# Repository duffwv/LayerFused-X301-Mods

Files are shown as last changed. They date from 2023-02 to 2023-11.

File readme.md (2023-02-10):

# LayerFused X301

These are my mods for the LayerFused X301.

* [Blind Joint](./blind-joint/)
* [BigTree-Tech Smart Filament Sensor Mount](./btt-smart-filament-sensor/)
* [BigTree-Tech TFT3.5 SPI Display Mount](./btt-tft35-spi-display-mount/)
* [BigTree-Tech Manta MB8 Mount](./electronics-enclosure/board-mounts/)
* [BigTree-Tech Mosfet Mount](./electronics-enclosure/board-mounts/)
* [Y and Z Modifications for MGN12C Carriage](./MGN12C/)
* [Webcam Mount](./webcam-mount/)
* [Bed-Leveling Mod for 6+2 Mod](./bed-leveling/)
* [Wago Holder](./electronics-enclosure/wago/)
* [4010 Fan Mount](./electronics-enclosure/40mm-fan-mount/)
* [Dual 4010 Fan Mount](./electronics-enclosure/dual-40mm-fan-mount/)
* [Mechanical Endstop Mount with Cutouts for Pins](./mechanical-endstop-mount/)
* [Y Homing Stop](./sensorless-homing/)

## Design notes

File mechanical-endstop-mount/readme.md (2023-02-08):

# Mechanical Z Endstop Mount with Cutouts for Pins/Solder on the Back

# Attribution

Original Part from Maker's Mashup: https://bitbucket.org/makersmashup/x301-models/src/master/STL/Mechanical%20Endstop%20Mount.stl

# License

https://creativecommons.org/licenses/by-sa/3.0/

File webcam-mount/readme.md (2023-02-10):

# Webcam Mount

A webcam mount to attach to the top 2020 extrusions with notches to overlap with 4mm corner plates.  

The design fits the space in my build between the center and front 2040 corner plate locations. I put 2040s at the default location and the 3z location.  There was only a small space to attach a webcam to the side of the 2020.

There are also mounts for a 4mm plate on just the left or right, and a flush mount.

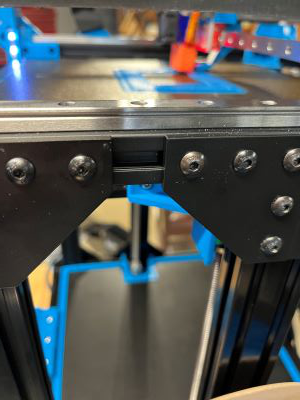
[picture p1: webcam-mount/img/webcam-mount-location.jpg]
Space for webcam


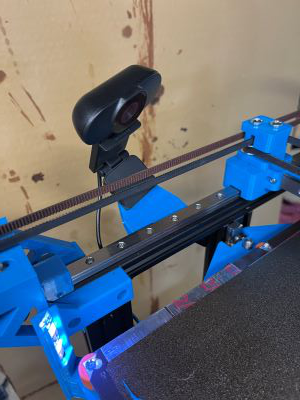
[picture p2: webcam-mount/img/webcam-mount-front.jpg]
Webcam Front


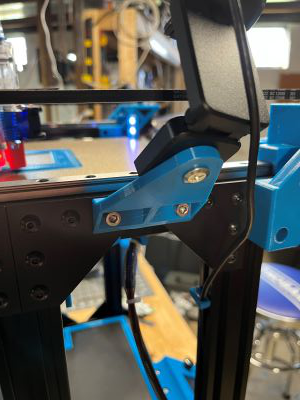
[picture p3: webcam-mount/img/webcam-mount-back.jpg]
Webcam Back


# License

https://creativecommons.org/licenses/by-sa/4.0/

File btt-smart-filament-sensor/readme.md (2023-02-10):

# BigTree Tech Smart Filament Sensor Mount

This is a modification of the BigTree Tech Smart Filament Sensor back for mounting on an extrusion.

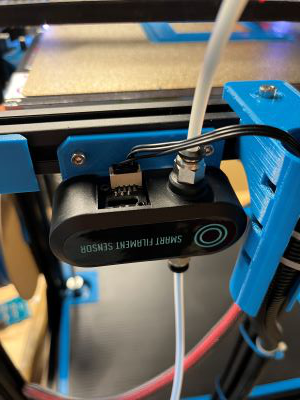
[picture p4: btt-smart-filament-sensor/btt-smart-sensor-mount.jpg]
BTT Smart Filament Sensor Mount


The source back is found at https://github.com/bigtreetech/smart-filament-detection-module/blob/master/STL/%E6%99%BA%E8%83%BD%E8%80%97%E6%9D%90%E6%A3%80%E6%B5%8B%E6%A8%A1%E5%9D%97-%E5%BA%95%E7%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

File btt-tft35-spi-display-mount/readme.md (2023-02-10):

# Display Mount for a BigTree Tech TFT3.5 SPI Display

Display Link: https://biqu.equipment/products/bigtreetech-tft35-spi-v2-1-touchscreen-io2can-module

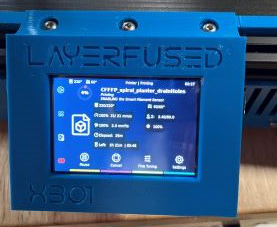
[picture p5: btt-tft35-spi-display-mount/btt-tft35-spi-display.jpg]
BigTree-Tech TFT35 SPI Display Mount


## Attribution

Original Part from Maker's Mashup: https://bitbucket.org/makersmashup/x301-models/src/master/STL/TFT24%20Display%20Case%20-%20LayerFused%20X301.stl

## License

https://creativecommons.org/licenses/by-sa/3.0/

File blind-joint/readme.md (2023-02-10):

# Blind Joint

Blind Joint setup for LayerFused X301.

## Drill Bit

I used a 7/32 drill bit, M6 Button Head screws (as appropriate for my extrusions), and a 4mm hex key.  Other extrusions may be tapped for M5 screws and a smaller hex key; therefore could accomodate a smaller drill bit.  If needed for your extrusions, tap opposite holes with appropriate tap; mine needed an M6 tap.

## Guides

* [Center Punch Guides for Extusion](./spacing_guides/extrusion-channel-center-punch-guides/)
* [Guides for Base Plate](./spacing_guides/base_plate_guide/)

## Rear Corner Brackets

The Rear Corner Brackets (https://bitbucket.org/makersmashup/x301-models/src/master/STL/Rear%20Corner%20Bracket%20Top%20v2.stl) can be installed by pushing them down below the joint access holes, tightening the joints, and then raising the bracket up.  The two inner corner T-Nuts on each corner bracket are changed to a sliding type T-nut (rather than the spinning hammer type), which are preloaded into the extrusions prior to attaching the blind joint.

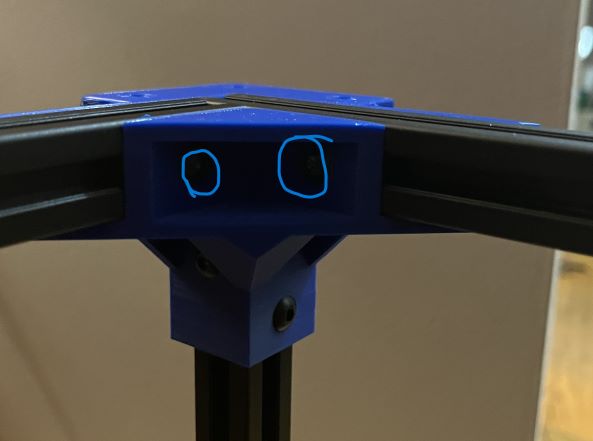
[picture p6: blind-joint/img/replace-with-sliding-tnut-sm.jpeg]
Replace T-Nuts for Corner Bracket


## Extrusion Access Holes

### Side 2080 and Side Top 2020 Access Holes for 2040 and 2020 Vertical Attachment

For attachment to 2040 Vertical drill an access hole at 170mm and 190mm from the front.  For a 3z mod where the 2040 is setback at 20mm from the front drill access holes at 30mm and 50mm. For the rear corner 2020 vertical drill an access hole 10mm from rear.

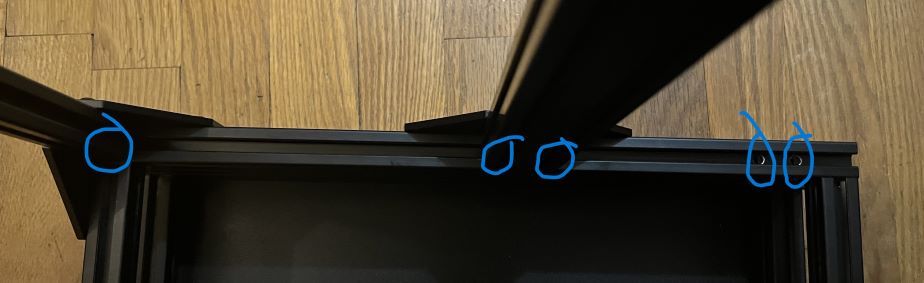
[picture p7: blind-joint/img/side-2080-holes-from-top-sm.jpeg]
2080 Holes from Top

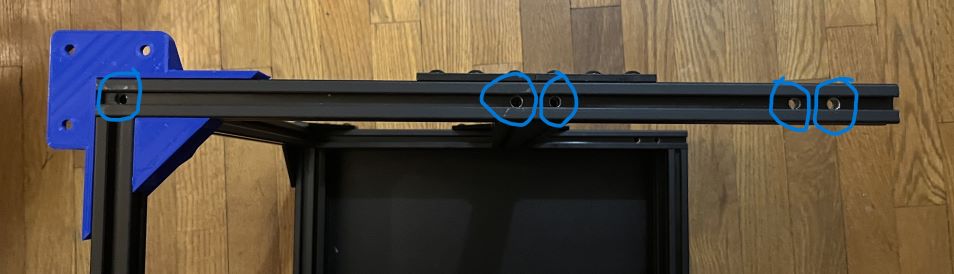
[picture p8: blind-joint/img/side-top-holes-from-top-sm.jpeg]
Side Top 2020 Holes from Top


### Side 2080 Access Holes for Front and Rear Attachment

In the top and bottom channel drill an access hole 10mm in from the edge on both sides; total of four holes per 2080.

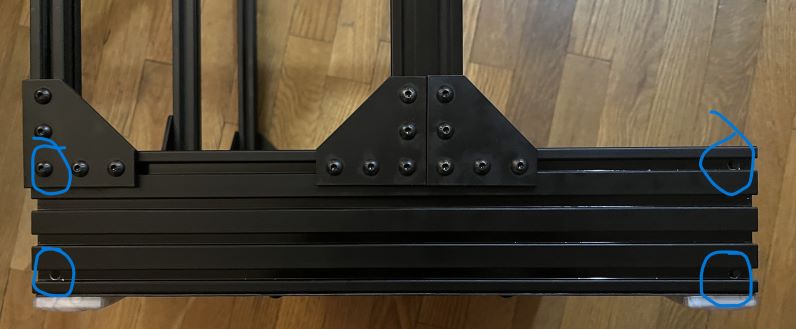
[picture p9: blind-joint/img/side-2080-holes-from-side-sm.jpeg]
2080 Holes from Side


### Side Top 2020 Access Holes for Rear Top 2020 Attachment

In the side top 2020s drill an access hole 10mm from the edge.

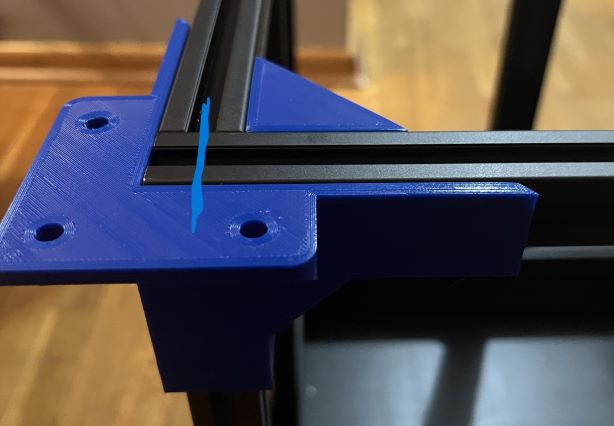
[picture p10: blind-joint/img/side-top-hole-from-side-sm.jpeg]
Side Top 2020 Hole from Side


### Rear Top 2020 and Rear Base Top 2020 Access Holes for Attachment to a 3z Vertical 2020

For 3z mod, in the 2020 drill an access hole 200mm (centered) for the 3z 2020 vertical.

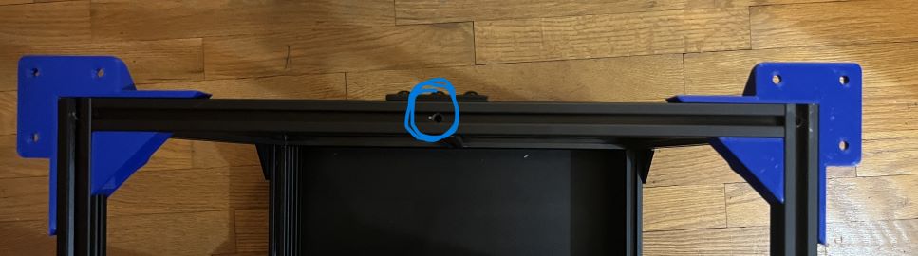
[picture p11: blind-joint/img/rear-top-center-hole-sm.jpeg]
Back Top 2020 Center Hole

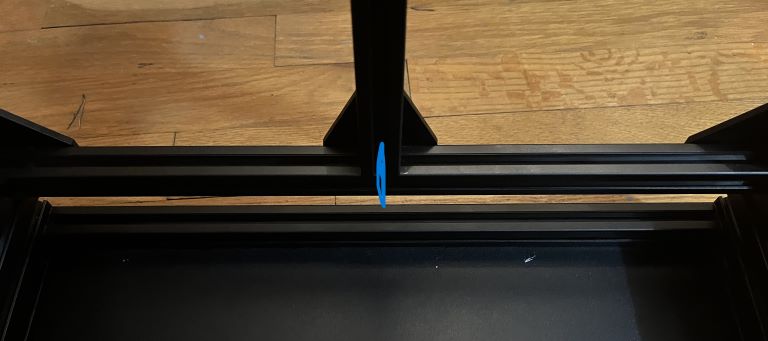
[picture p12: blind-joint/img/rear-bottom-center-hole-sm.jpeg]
Back Bottom 2020 Center Hole


### Bed Frame Access Holes

In the bed side 2020s, drill an access hole 150mm (centered); this makes the H frame of the bed.

For a 6+2 mod, also drill holes 10mm from each end of the bed side 2020s.

## Base Plate

The base plate can, optionally, be drilled with access holes for the sides which coorespond to the access holes for the 2080 attachment to verticals.

If the base plate is drilled the use of sliding style t-nuts and [spacers](./base-sliding-tnut-spacers/) can help with the danger of losing t-nuts when accessing the blind joints, because some access hole positions are underneath the feet.

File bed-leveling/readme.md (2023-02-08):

# Bed Leveling

## Bed Leveling Shim

For putting under silicone leveling columns to address bed warp, etc. I needed extra space for insulation I installed to the bottom of the heatbed.

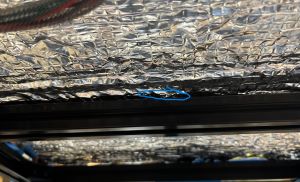
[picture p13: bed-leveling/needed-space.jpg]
Needed extra space for insulation


## Bed Screw Plate

A small part to put into the underside channel of the 2020 extrusion under the side center mounting holes to support a thumbscrew.  I drilled holes through the center of the 2020 extrusions of the bed frame so that the mounting screw goes all the way through the frame, through the screw plate and attached with a thumb screw on the bottom.  I also used a cut silicone mount similar to the ones described here: https://wiki.layerfused.com/en/printers/mods/johanmalay/8-point-bed-mount

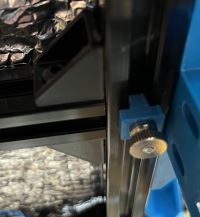
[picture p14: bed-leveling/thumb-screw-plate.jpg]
Plate for Thumbscrew on Side Center Screws


## Bed Hole Placement

An image I found on an image search (source unknown, image watermarked SWMaker).

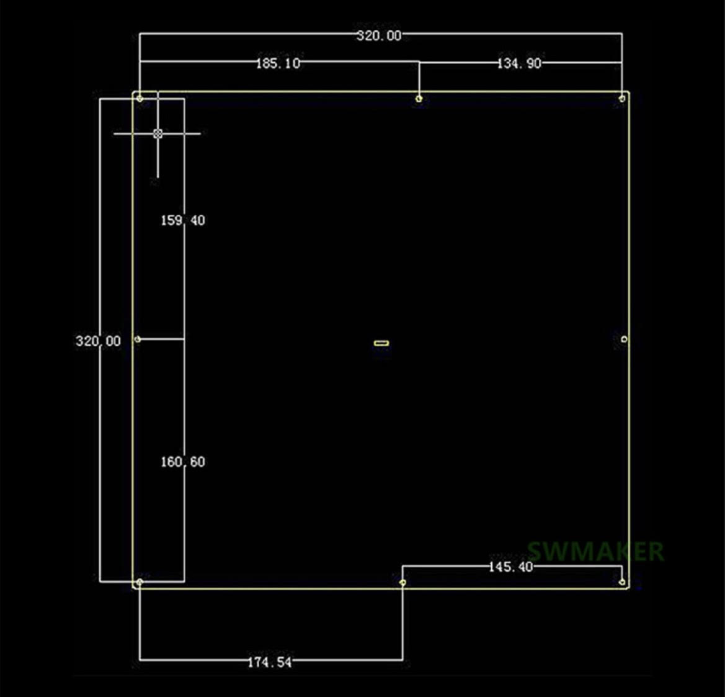
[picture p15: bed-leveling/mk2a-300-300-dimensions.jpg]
mk2a 300mm by 300mm bed dimensions


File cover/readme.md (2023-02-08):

# Corregated Plastic Cover

*** DRAFT ***

*This is a draft.  I used these parts, but am not very happy with them.  If I ever need to redo this, I will try modifications*

Cut correcgated plastic to dimensions accounting for 2.5mm edge cover thickness plus some tolerance.  The wings on the edge cover are 7.5mm to cover some amount of play.

So cut a rectangle approx 394mm by 354mm for the 400mm by 360mm area.  That is 400/360mm - 2.5 for each side and 1mm tolerance.

For the steppers in the standard 2z configuration, center the cutout at 150mm (minus any tolerance, so 149mm-ish) from the front edge. The part for the cutout is 45mm wide, so the cutout needs to be at least 50mm wide plus some tolerance.  The depth of the hole is meant to be 45mm in, so make that cut 47.5 plus some tolerance.

Here are the parts needed:

* 47.5mm by 27.5mm corner (outside dimension 50 x 30) X 2
* 149mm straight part for the front and back X 4
* 139mm straight part for the sides behind the steppers X 2
* 89mm straight part for the sides in front of the steppers X 2
* 10mm corners for the transition from the steppers to the straight sides X 4

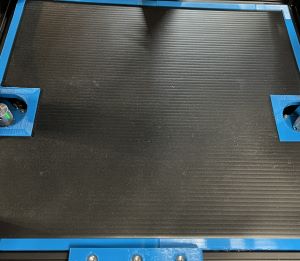
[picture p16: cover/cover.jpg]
Cover with Edges


## Changes needed

* The pinch is set to 1mm tighter than the width of the corregated plastic, which fit good with the test part, but was too much friction on the larger pieces (I had to "lightly" hammer some parts in place).  Might try 0.75 or 0.50 instead.
* Considering merging the 10mm corners with the stepper arches.  Especially if loosing the pinch, as those small corners don't have the same bite area, and may be too loose on their own.
* Integrating options for small wire paths, somehow.

# Stock Cover Dimensions and Source

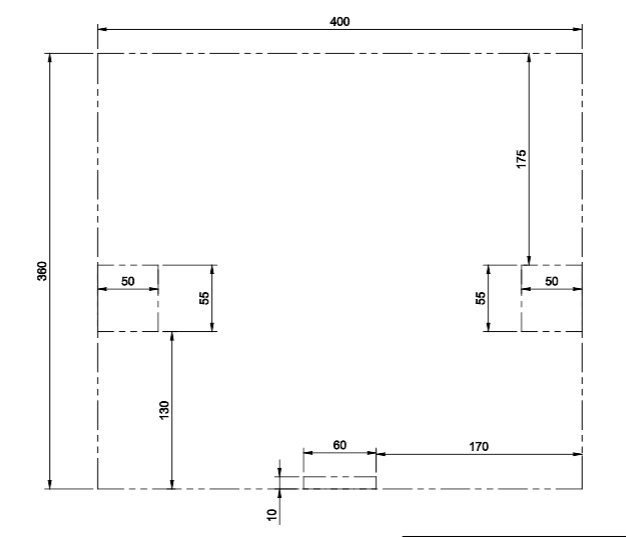
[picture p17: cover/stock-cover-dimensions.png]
Stock Cover Dimensions


https://bitbucket.org/makersmashup/x301-models/src/master/DWG/Acrylic%20Cover%20Drawing.dwg

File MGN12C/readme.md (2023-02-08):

# MGN12C Mods

Modifications to parts to accept MGN12C carriage blocks in addition to the MGN12H blocks.

# Attribution

Originial parts by Makers Mashup. https://bitbucket.org/makersmashup/x301-models/src/master/

# License

https://creativecommons.org/licenses/by-sa/3.0/

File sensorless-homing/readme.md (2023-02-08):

# Y Homing Stop

On my build, the Y homing was about -25mm from the print origin, and the BLTouch mount I used was hitting the LED/Neopixel mount on the bed frame when homing.  This spacer is put on the front of X/Y Stepper so that the Y homes about -5mm from the origin and prevents the BLTouch mount from hitting other components.

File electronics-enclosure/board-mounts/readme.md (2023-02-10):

# Board Mounts

* Big Tree Tech Manta M8P
* Large Mosfet

Screw holes of STLs setup for #6-32 motherboard standoffs.

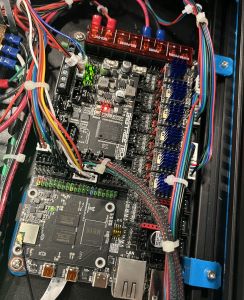
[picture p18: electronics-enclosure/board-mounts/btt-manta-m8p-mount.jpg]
BTT Manta M8P Mount

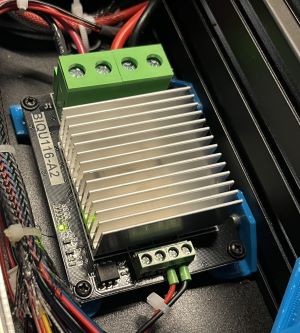
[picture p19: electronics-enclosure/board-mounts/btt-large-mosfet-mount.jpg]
Large Mosfet Mount


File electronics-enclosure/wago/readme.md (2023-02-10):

# Wago Holder

A holder for two 3 wire, lever Wago connectors (input Line and Neutral and output each to two power supplies).  

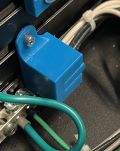
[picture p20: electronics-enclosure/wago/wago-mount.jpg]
Wago Mount


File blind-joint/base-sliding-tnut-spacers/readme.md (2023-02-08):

# Spacers

When base plate has access holes drilled for the blind joints, a couple of access holes are covered by the feet.  Since the feet need removed to access those holes there is a chance of losing the t-nuts inside the extrusion (particularly the front and back ones) and getting them lined back up would be difficult.  Switching the plate mounting to use sliding type t-nuts (instead of the spinning hammer type) and using spacers to help keep them aligned inside the extrusions may help with this problem.

The base plate is 440mm across the front and back and 400mm on the sides.  The feet attach 30mm in from each corner.  Across the front and back, I put holes for attachment 145mm from each edge.  Along the sides, I put holes at 135mm from each edge.

There are blind joint access holes along the sides.  One is under the foot at 30mm for a 2040 vertical with a hole also at 50mm; this is for a 20mm setback for a 3z setup.  Spacers for a 3z at a 40mm setback are not included. There are access holes at 170mm and 190mm for the 2040 vertical at its standard 2z setup.  There is a 10mm access hole from the back (under the back foot) for the rear corner 2020s.

M5 sliding t-nut (specs are 10mm wide, actual measured 9.5mm)

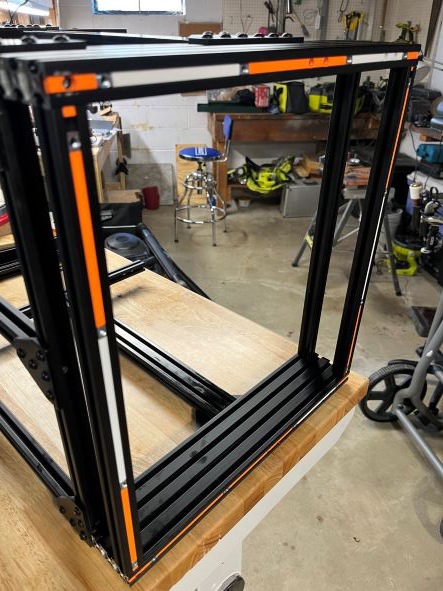
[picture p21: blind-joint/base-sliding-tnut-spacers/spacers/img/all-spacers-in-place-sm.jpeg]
Bottom of X301 with T-Nuts and Spacers


## Front and Back Order

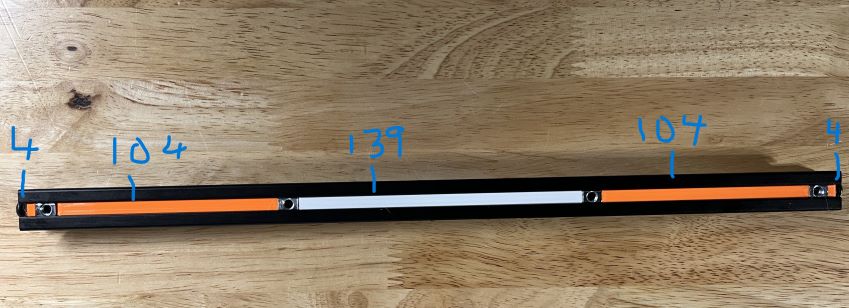
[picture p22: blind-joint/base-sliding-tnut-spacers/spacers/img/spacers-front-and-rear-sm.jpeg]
Front and Back Extrusion with Spacers and T-Nuts


1. 4mm spacer
2. t-nut (foot 30mm)
3. 104mm spacer
4. t-nut (145mm from edge)
5. 139mm spacer
6. t-nut (145mm from far edge)
7. 104mm spacer
8. t-nut (foot 30mm)
9. 4mm spacer

## Side Order (From the Front)

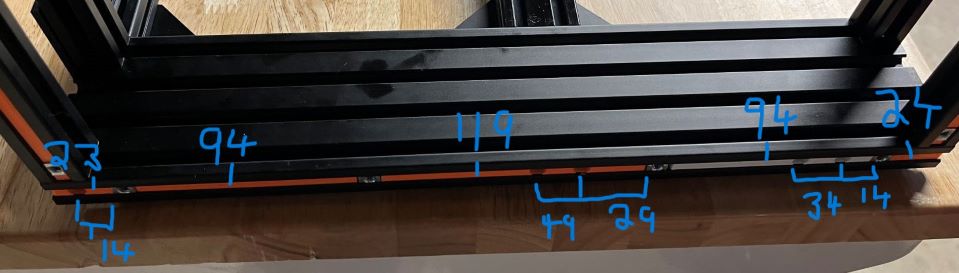
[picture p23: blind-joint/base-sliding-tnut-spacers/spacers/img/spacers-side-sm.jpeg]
Side Extrusions with Spacers and T-Nuts


1. 24mm spacer (only if there are end covers and if the end covers don't interfer)
2. t-nut (foot and access hole 30mm)
3. 94mm spacer with access holes at 14mm and 34mm (3z position 20mm setback) from edge of spacer
4. t-nut (135mm from front)
5. 119mm spacer with access holes at 29mm and 49mm (2z stock position)
6. t-nut (135mm from back)
7. 94mm spacer
8. t-nut (foot 30mm from back)
9. 23mm spacer with access holes at 14mm (10mm from back for back corner verticals, only if there are end covers and if the end covers don't interfer)

## Accessing the Rear Corner Blind Joint

1. Slightly loosen the Foot Screw along the back, but don't remove.
2. Completely unscrew the Foot Screw along the side and allow the foot to swing away.
3. Insert hex key into the access hole.

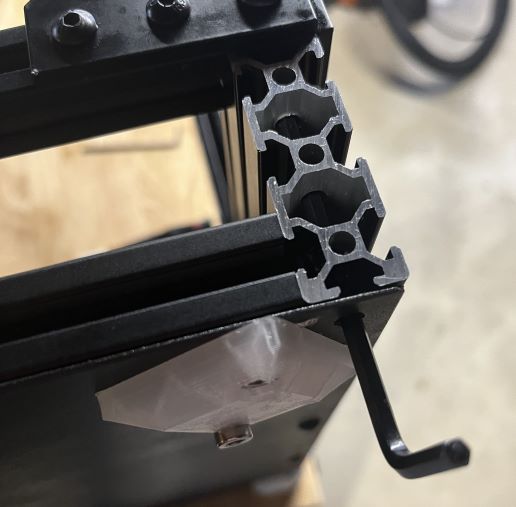
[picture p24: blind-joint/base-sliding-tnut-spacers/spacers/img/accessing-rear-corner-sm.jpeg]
Accessing the Rear Corder Blind Joint


## Accessing the Front Z Blind Joint at 30mm

1. Slightly loosen the Foot Screw along the front, but don't remove.
2. Completely unscrew the Foot Screw along the side and allow the foot to swing away.
3. Use a screwdriver, pick, or another similar tool to slide the t-nut out of the way.
4. Insert hex key into the access hole.

Accessing the Front Z Blind Joint

## Accessing Other Blind Joint Holes

The other holes can be accessed directly, although the spacers may need to be slid back into place due to tolerances built into the length of the spacers.

Accessing the 50mm Hole
Accessing the 170mm Hole

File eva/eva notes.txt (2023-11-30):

top of eva: 10mm
rail and carriage: 13mm
2020: 20

total from top of eva to base of 2020: 43mm

Back upper to lower center to center: 13mm

Top to upper back center 27.6

 back hole: 11.2, sep 1.8, total inner: 24.2

front grabber hole: 10mm: total 23mm, 3mm sep

Eva Top to Top Center Pully 27.6
Top Center Pully to Bottom Center PUlly: 13
Eva Top to Bottom Center Pully 40.6

Eva Front to Back Center: 48.4

Center to BAck center: 22.05
Center to Front center: 26.35

|  8.5  |  9.5 |

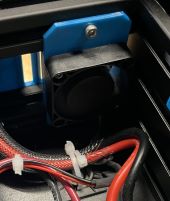
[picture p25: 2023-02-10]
electronics-enclosure/40mm-fan-mount/4010-mount.jpg

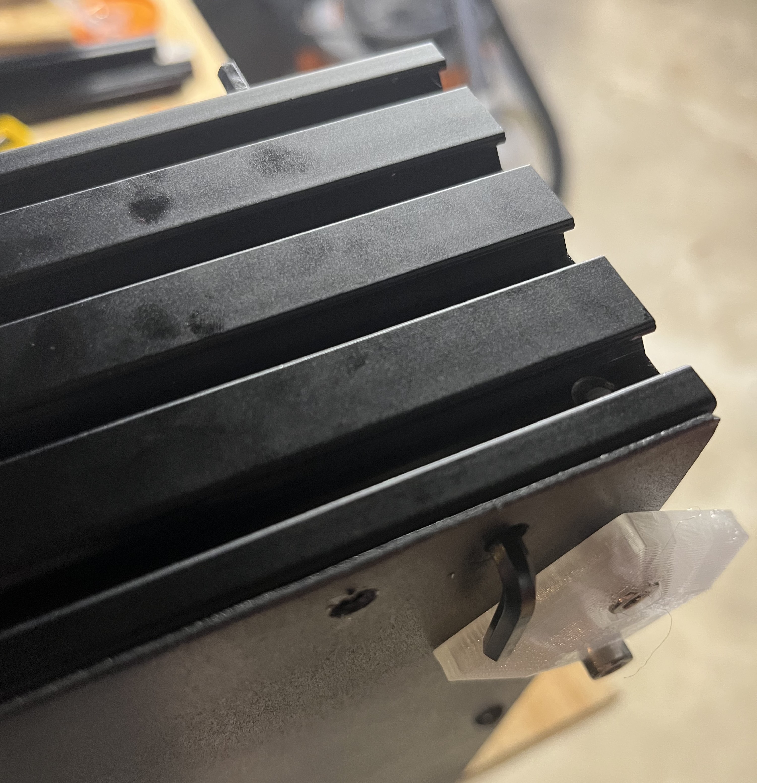
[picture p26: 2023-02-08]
blind-joint/base-sliding-tnut-spacers/spacers/img/accessing-30mm-front-z.jpeg

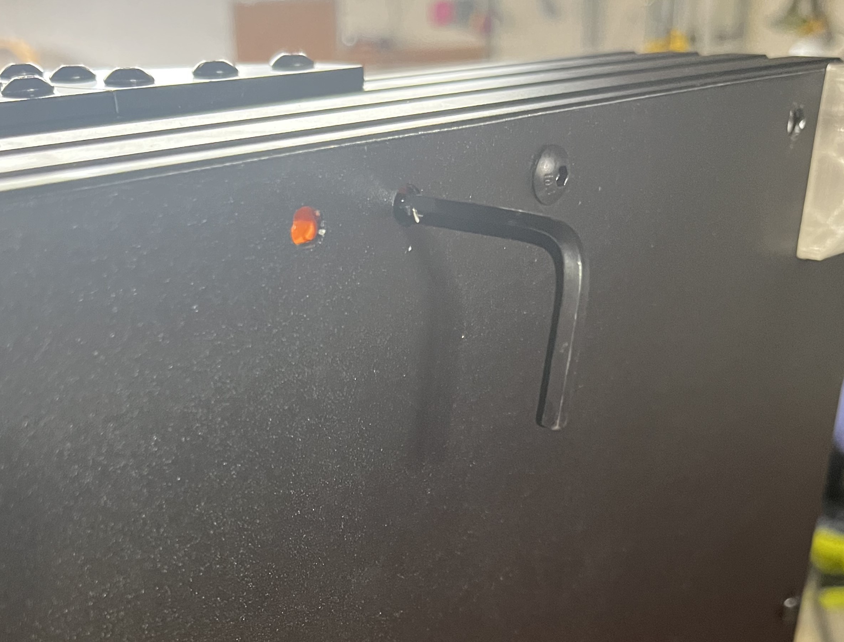
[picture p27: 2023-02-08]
blind-joint/base-sliding-tnut-spacers/spacers/img/accessing-170mm.jpeg

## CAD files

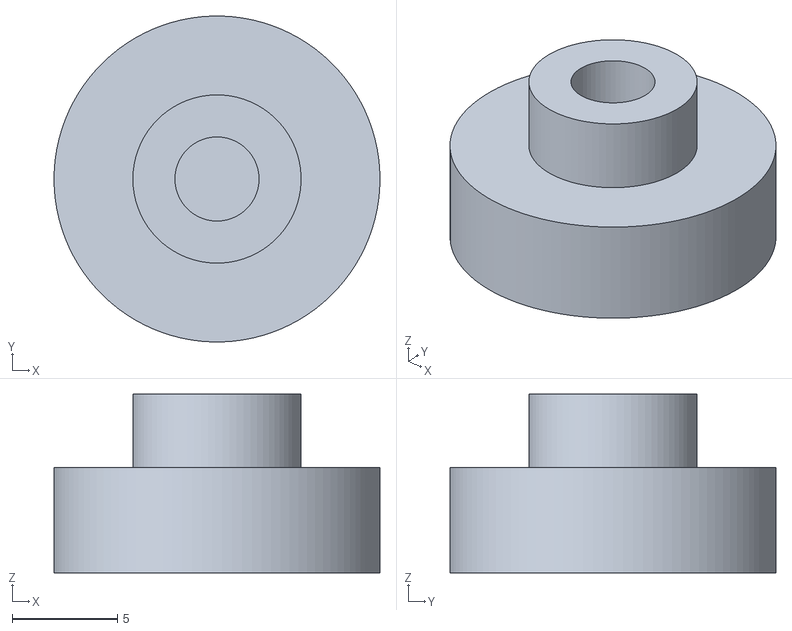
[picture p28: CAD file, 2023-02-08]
bed-leveling/bed-leveling-column-5mm-extension.stl
15.5 x 15.5 x 8.50

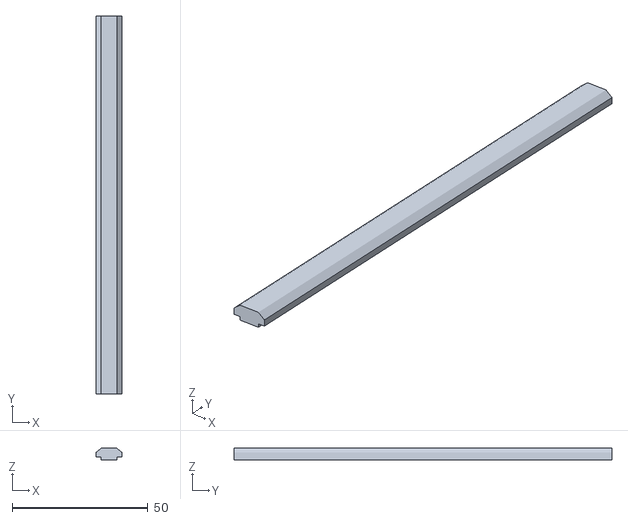
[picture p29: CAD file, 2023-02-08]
blind-joint/base-sliding-tnut-spacers/spacers/STL/frontandback440mm/base-spacer-front-back-139.stl
9.50 x 139.0 x 4.25

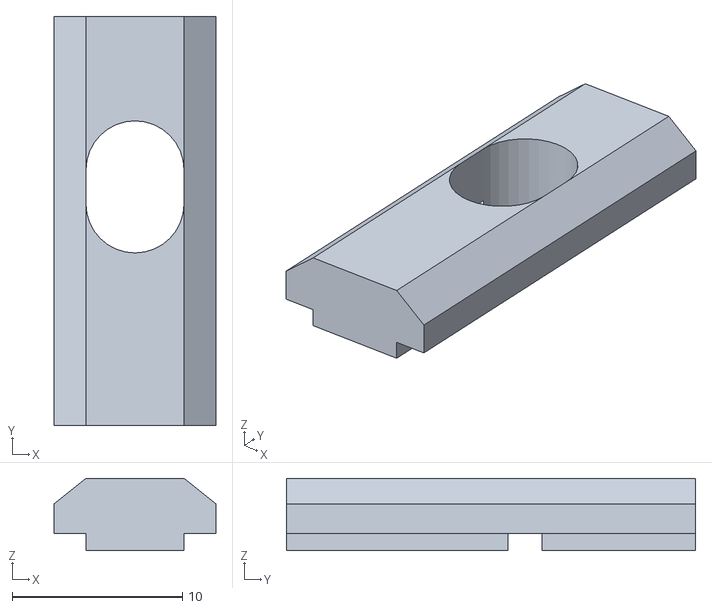
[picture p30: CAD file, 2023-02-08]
blind-joint/base-sliding-tnut-spacers/spacers/STL/side400mm/base-spacer23mm-14mm.stl
9.50 x 24.0 x 4.25

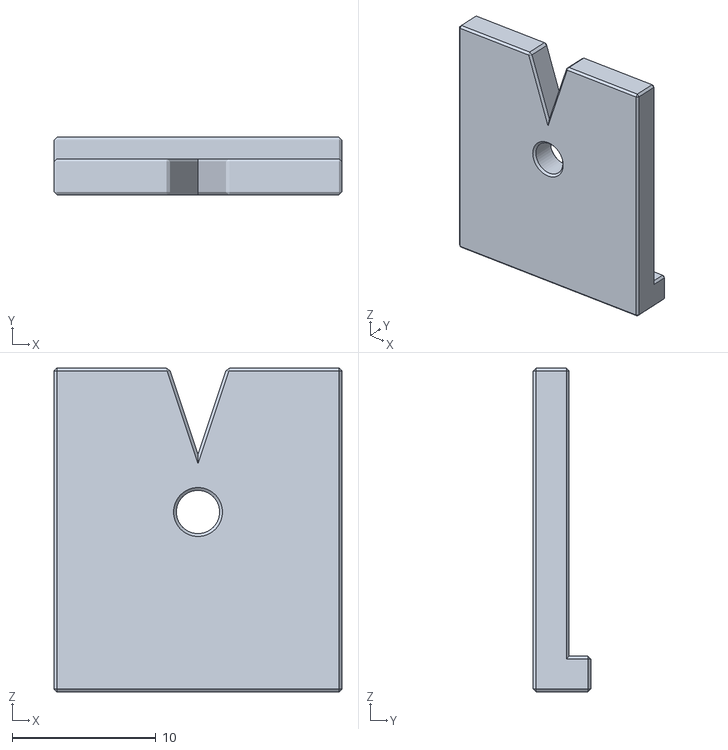
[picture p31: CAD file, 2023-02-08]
blind-joint/spacing_guides/base_plate_guide/guide-10mm-edge-plate v3.stl
20.0 x 4.00 x 22.5

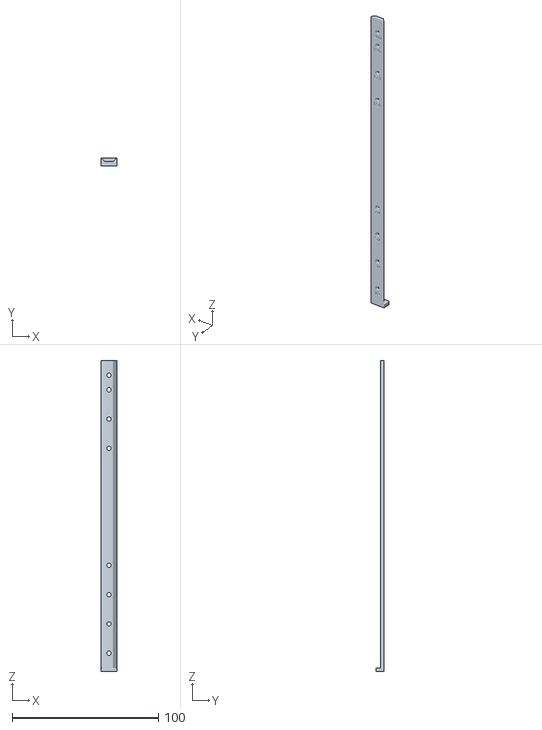
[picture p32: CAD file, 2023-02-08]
blind-joint/spacing_guides/extrusion-channel-center-punch-guides/blind-joint-drill-guide-z-moddedZ-and-center v10.stl
10.8 x 5.50 x 212.5

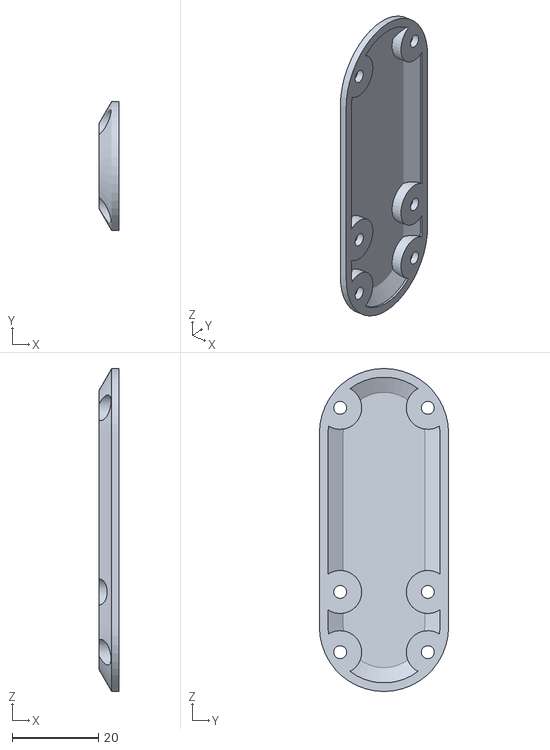
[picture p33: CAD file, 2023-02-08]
btt-smart-filament-sensor/btt-original-back/btt-smart-filament-sensor-back.STL
4.55 x 30.0 x 75.0

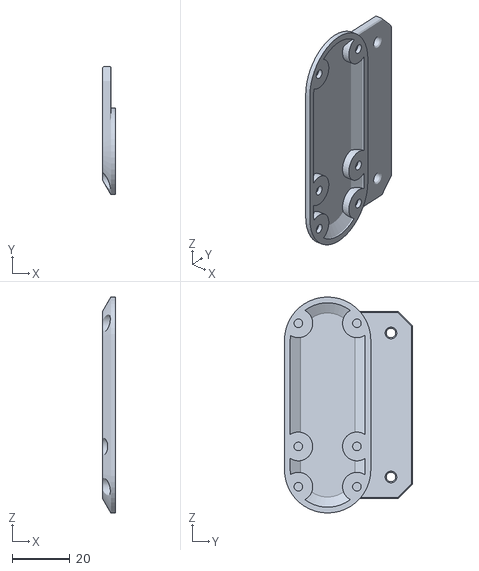
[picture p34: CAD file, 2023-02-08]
btt-smart-filament-sensor/btt-smart-filament-sensor-mount.stl
4.55 x 44.5 x 75.0

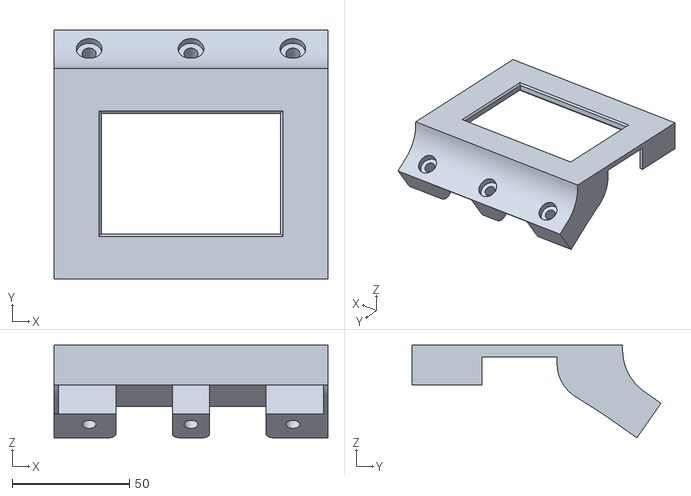
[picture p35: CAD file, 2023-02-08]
btt-tft35-spi-display-mount/TFT35 SPI Display Case - No Text.stl
117.0 x 106.4 x 39.6

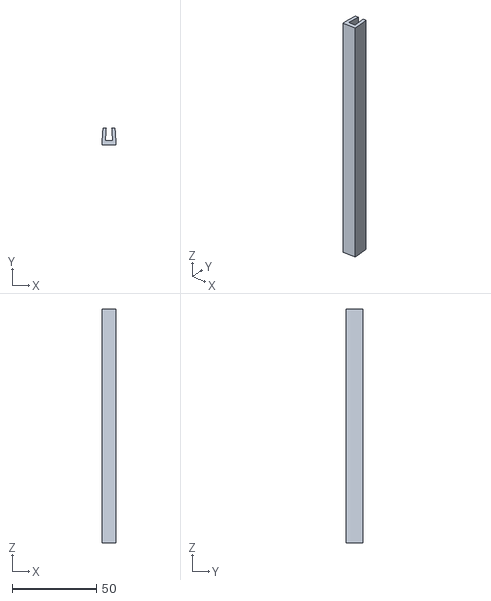
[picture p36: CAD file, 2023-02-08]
cover/1mm-pinch/cover-edges-straight-139.stl
8.25 x 10.0 x 139.0

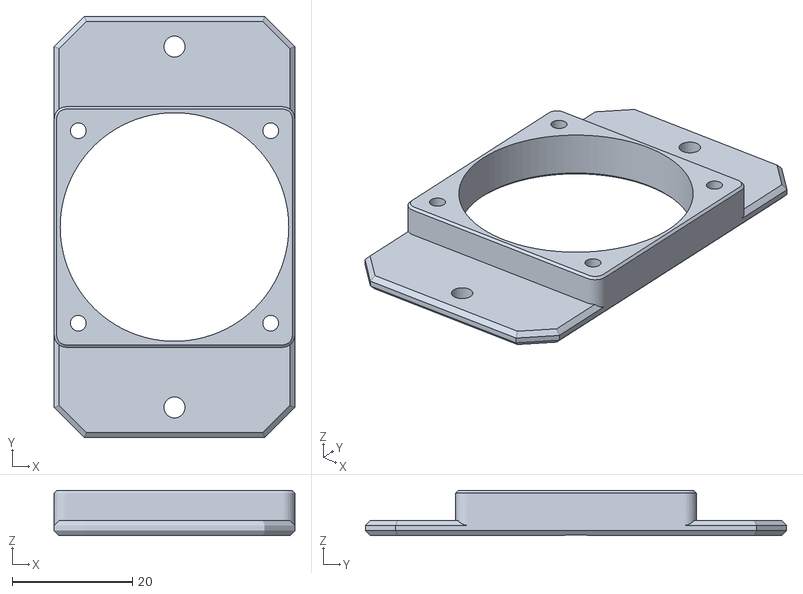
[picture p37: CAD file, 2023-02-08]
electronics-enclosure/40mm-fan-mount/40mm-fan-mount.stl
40.0 x 70.0 x 7.50

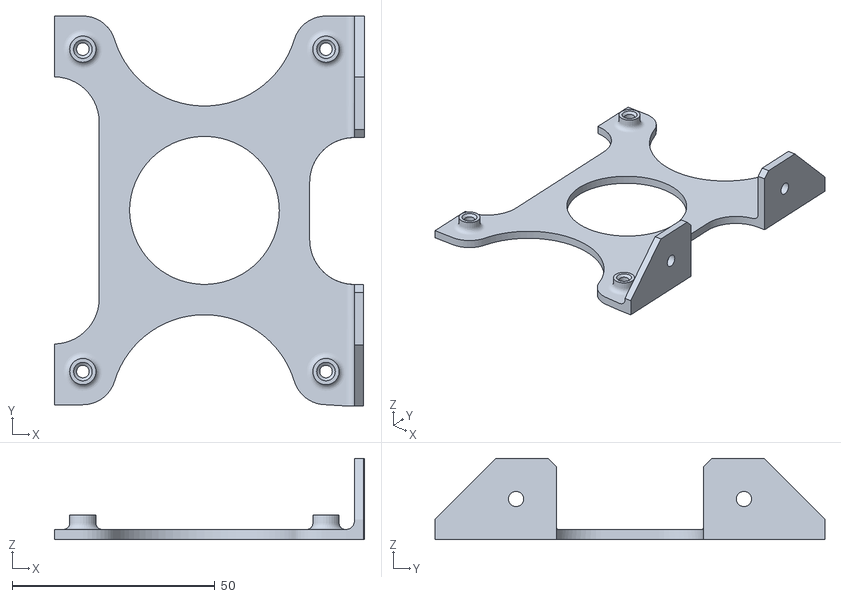
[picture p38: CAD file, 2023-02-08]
electronics-enclosure/board-mounts/large-mosfet.stl
76.5 x 96.2 x 20.0

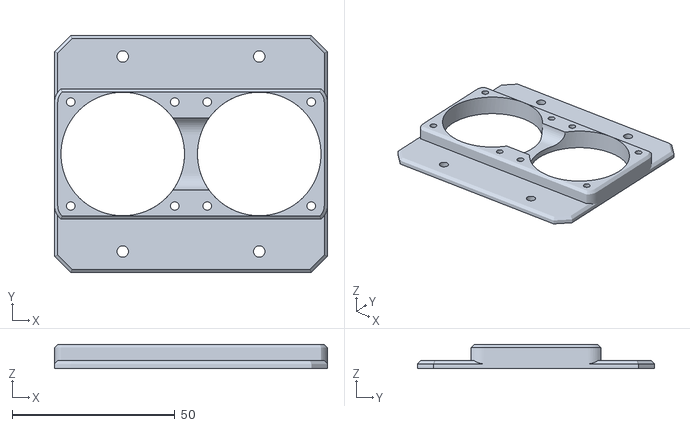
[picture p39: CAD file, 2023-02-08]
electronics-enclosure/dual-40mm-fan-mount/dual-40mm-fan-mount.stl
84.0 x 73.0 x 7.50

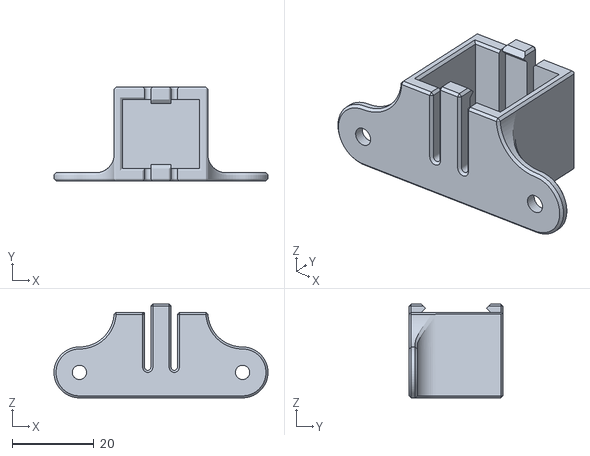
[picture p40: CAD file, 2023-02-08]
electronics-enclosure/wago/wago.stl
52.5 x 23.0 x 23.0

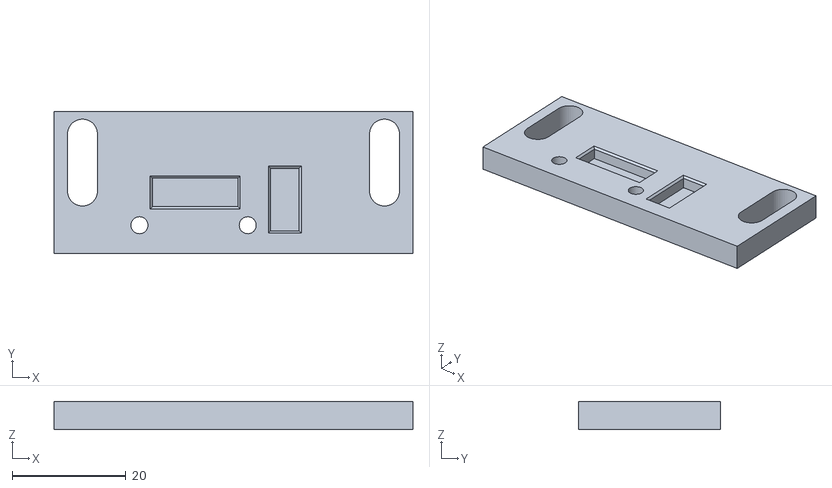
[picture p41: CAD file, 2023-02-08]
mechanical-endstop-mount/Mechanical Endstop Mount.stl
63.0 x 25.0 x 5.00

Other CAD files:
MGN12C/XY Bracket Bottoms V2 Left.stl
sensorless-homing/y-homing-stops v2.stl
webcam-mount/stl/webcam-mount-plate-right.stl
bed-leveling/bed-leveling-column-shim-1mm.stl
MGN12C/XY Bracket Bottoms V2 Right.stl
MGN12C/XY Bracket Bottoms V2.f3d
MGN12C/Z Carriage Bracket.f3d
MGN12C/Z Carriage Bracket.stl
bed-leveling/bed-leveling-column-shim-2mm.stl
bed-leveling/bed-screw-plate.f3d
bed-leveling/bed-screw-plate.stl
blind-joint/base-sliding-tnut-spacers/spacers/Fusion/base-spacer.f3d
blind-joint/base-sliding-tnut-spacers/spacers/STL/frontandback440mm/base-spacer-4mm.stl
blind-joint/base-sliding-tnut-spacers/spacers/STL/frontandback440mm/base-spacer-front-back-104.stl
blind-joint/base-sliding-tnut-spacers/spacers/STL/side400mm/base-spacer-119mm-slot29-slot49.stl
blind-joint/base-sliding-tnut-spacers/spacers/STL/side400mm/base-spacer-24mm.stl
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

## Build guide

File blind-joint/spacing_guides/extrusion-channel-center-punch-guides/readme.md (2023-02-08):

# Center Punch Guides for Extrusions

Printable guides for using a center punch in 20 series extrusions.  These are tight in my extrusions both in the channel and against my center punch tip so that the punch is as accurate in the channel as possible.

## Side Extrusions (bottom and top) (measured from the front)

30mm & 50mm is for the 2040 blind joint access if using 3z mod (https://wiki.layerfused.com/en/printers/mods/johanmalay/3-z-screw-conversion) with 20mm setback

50mm & 70mm is for the 2040 blind joint access if using 3z mod (https://wiki.layerfused.com/en/printers/mods/johanmalay/3-z-screw-conversion) with 40mm setback

170mm & 190mm is for the 2040 blind joint access for the default build

## 3z rear 2020 (measured from either side)

200mm is for centering the third z vertical 2020. (if using a 2040 for the thrid z vertical, should be able to use 190 from both sides)

## Bed Frame

150mm for centering the standard H frame 

10mm for end extrusions if using the 6+2 point mod (https://wiki.layerfused.com/en/printers/mods/johanmalay/8-point-bed-mount)

## All others joining at corners

10mm for joining corners

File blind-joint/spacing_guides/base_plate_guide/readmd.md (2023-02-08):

# Base Plate Guide for Holes

Printable SVG for placing center punch for drilling holes.

Trim on lines, align to corner of plate, and punch appropriate holes.

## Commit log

2023-02-10 added images and links
    [TFT35 SPI Display Case - LayerFused X301.f3d, TFT35 SPI Display Case - LayerFused X301.stl, TFT35 SPI Display Case - No Text.stl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]
2023-02-10 removed old fusion file
    [TFT35 SPI Display Case - LayerFused X301.f3d]
